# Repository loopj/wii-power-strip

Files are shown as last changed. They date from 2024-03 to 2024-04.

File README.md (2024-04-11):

<p align="center">
  
  
</p>

<h3 align="center">Slimline PCB to supply power to trimmed Wii motherboards</h3>

<p align="center">
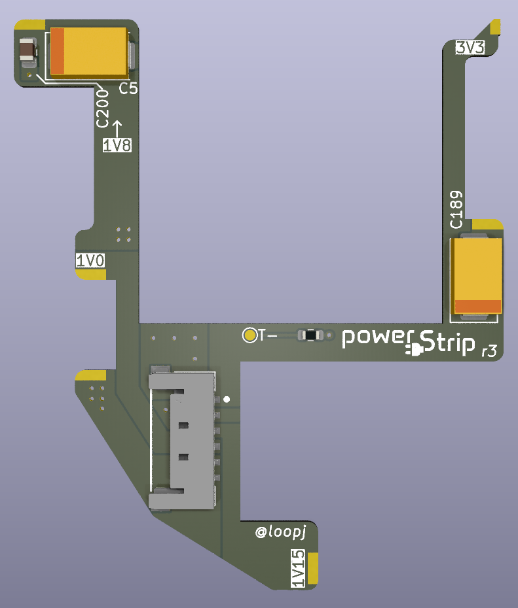
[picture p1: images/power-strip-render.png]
  
</p>

## Features

- Solders directly onto the top of a Wii motherboard
- Supplies power to the 1V, 1.15V, 1.8V, and 3.3V points
- Power connector allows for modular builds without soldering/desoldering wires
- Adds pads for the relocation of capacitors (C5, C189, C200) typically removed on more aggressive trims
- Pad for an optional thermistor, for compatibility with [4Layer Technologies RVL-PMS](https://4layertech.com/products/rvl-pms-2)
- Fits entirely within the outline of an Omega trim
- Fits under heatplates/heatsinks

## Parts / Ordering

- Grab the Gerber files for the [latest release](https://github.com/loopj/wii-power-strip/releases/latest)
- Order a 2-layer, 0.6mm PCB from JLCPCB or similar fab
- Purchase a 6-pin Molex Pico-Lock connector, PN 504050-0691 ([DigiKey](https://www.digikey.com/en/products/detail/molex/5040500691/4357148), [Mouser](https://www.mouser.com/ProductDetail/Molex/504050-0691?qs=bvCPb%252BE7ys2K1LQC9e%2FvRg%3D%3D))
- Purchase either a pre-assembled cable, or parts to crimp your own
  - 50mm pre-assembled cable, PN 15132-0600 ([DigiKey](https://www.digikey.com/en/products/detail/molex/0151320600/7423256), [Mouser](https://www.mouser.com/ProductDetail/Molex/15132-0600?qs=HXFqYaX1Q2wQ%2F2lUgfK5Kw%3D%3D))
  - 100mm pre-assembled cable, PN 15132-0601 ([DigiKey](https://www.digikey.com/en/products/detail/molex/0151320601/7423257), [Mouser](https://www.mouser.com/ProductDetail/Molex/15132-0601?qs=HXFqYaX1Q2xvCBLpk4R9sg%3D%3D))
  - Connector, PN 504051-0601 ([DigiKey](https://www.digikey.com/en/products/detail/molex/5040510601/4357150), [Mouser](https://www.mouser.com/ProductDetail/Molex/504051-0601?qs=bvCPb%252BE7ys2KoBFgs2%2FzNw%3D%3D))
  - Crimp terminals, PN 504052-0098 ([DigiKey](https://www.digikey.com/en/products/detail/molex/5040520098/4357152), [Mouser](https://www.mouser.com/ProductDetail/Molex/504052-0098-Cut-Strip?qs=lzT3SgJKZn3tXLBIQ9V4FQ%3D%3D))
- Optional - 10KΩ thermistor with a 3380K B value, in an 0603 SMD package

## Installation

- If you are doing a motherboard trim that will trim off C5 or C189, desolder these and save them
- If you are doing a NAND relocation which removes C200, desolder this and save it
- Solder the connector and any rescued capacitors to the board by hand or using a hot plate
- Place board on the Wii motherboard, it should self-align
- Solder the pads on the edge of the board to the Wii motherboard
  - 1V0 to the top of C143
  - 1V15 to the left of C17
  - 1V8 to the via array at the top left. You may wish to scratch away some solder mask to have more copper to solder to.
  - 3V3 to the top of C128
  - GND to the bottom of C180 and C143
- Use plenty of solder and flux!

## C189 height

Some motherboard revisions have a very tall (~2.9mm) C189 capacitor, which can interfere with heatplates if you are relocating it. If you have one of these boards, you may wish to consider purchasing a lower profile capacitor. As long as it is a 220uF, 6.3V+, 2917 or 2312 SMD package capacitor it should work fine. The Kyocera AVX NOJY227M006RWJ is a low profile version of the original cap used on the Wii. The TAJX227K006RNJ or TAJY227K006RNJ should also both work.

## RVL-PMS Companion Board

If you want to use Power Strip with the 4Layer Technologies [RVL-PMS-2](https://4layertech.com/products/rvl-pms-2), or [RVL-PMS-Lite](https://4layertech.com/products/pms2-lite) boards, [Y2K](https://github.com/y2k-x) has kindly designed a carrier board called the *Power Strip PMS Companion*, which is included in this repository for convenience.

You can read more about it in the [pms-companion](pms-companion) directory.

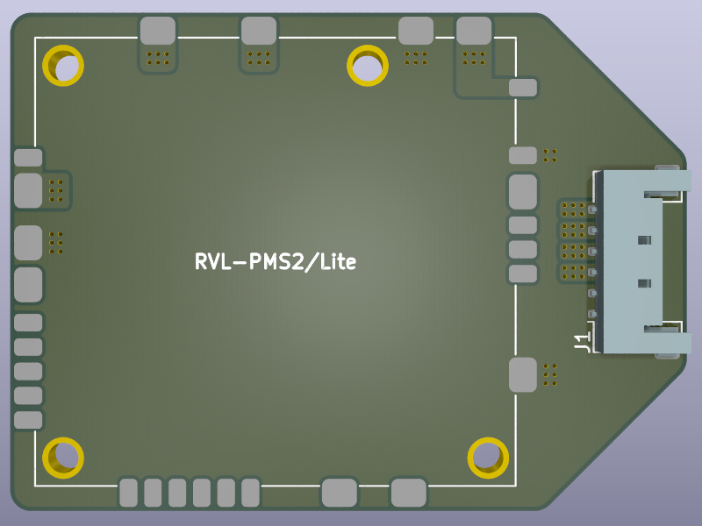
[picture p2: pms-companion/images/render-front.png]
Power Strip PMS Companion


## License

Permissively released under the Solderpad Hardware License v2.1

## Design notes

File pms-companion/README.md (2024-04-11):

# Power Strip PMS Companion

A carrier board for the 4Layer Technologies [RVL-PMS-2](https://4layertech.com/products/rvl-pms-2), or [RVL-PMS-Lite](https://4layertech.com/products/pms2-lite) boards which adds a pico-lock connector for the Wii Power Strip. Designed by [Y2K](https://github.com/y2k-x).

Power Strip PMS Companion front

## Parts / Ordering

- Grab the Gerber files from the [latest release](https://github.com/loopj/wii-power-strip/releases/latest)
- Order a 2-layer PCB from JLCPCB or similar fab, of desired thickness
- Order a [RVL-PMS-2](https://4layertech.com/products/rvl-pms-2) or [RVL-PMS-Lite](https://4layertech.com/products/pms2-lite)
- Purchase a 6-pin Molex Pico-Lock connector, PN 504050-0691 ([DigiKey](https://www.digikey.com/en/products/detail/molex/5040500691/4357148), [Mouser](https://www.mouser.com/ProductDetail/Molex/504050-0691?qs=bvCPb%252BE7ys2K1LQC9e%2FvRg%3D%3D))

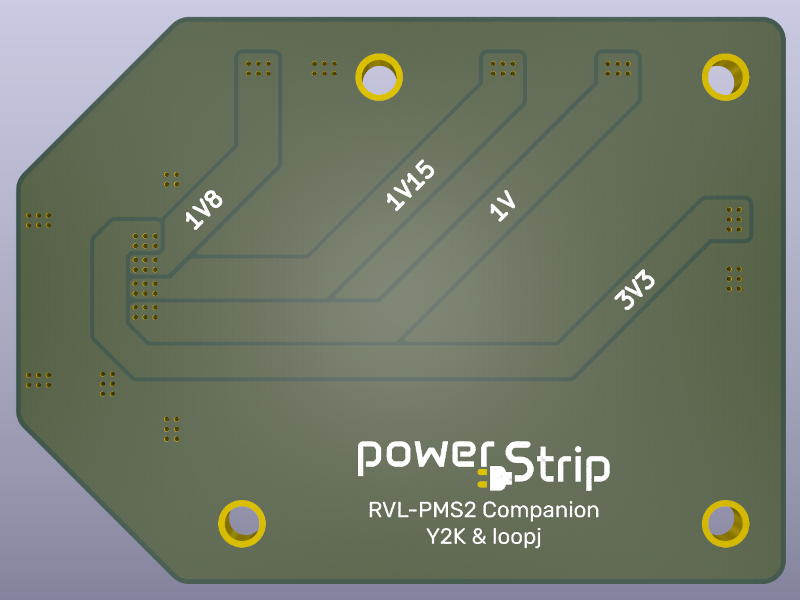
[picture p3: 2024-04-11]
pms-companion/images/render-back.png

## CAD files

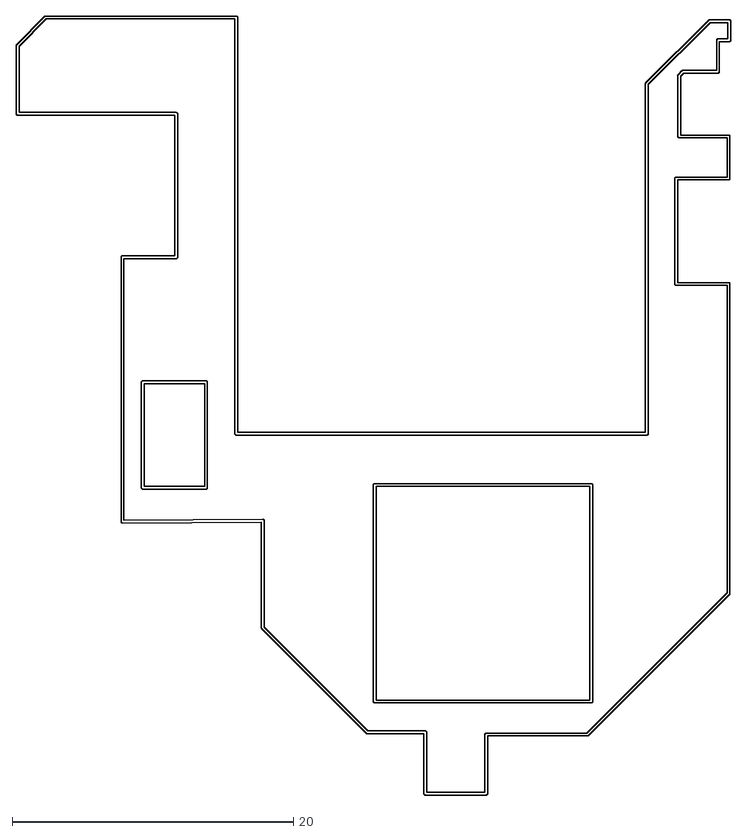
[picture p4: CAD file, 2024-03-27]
images/full-outline.dxf
50.8 x 55.4

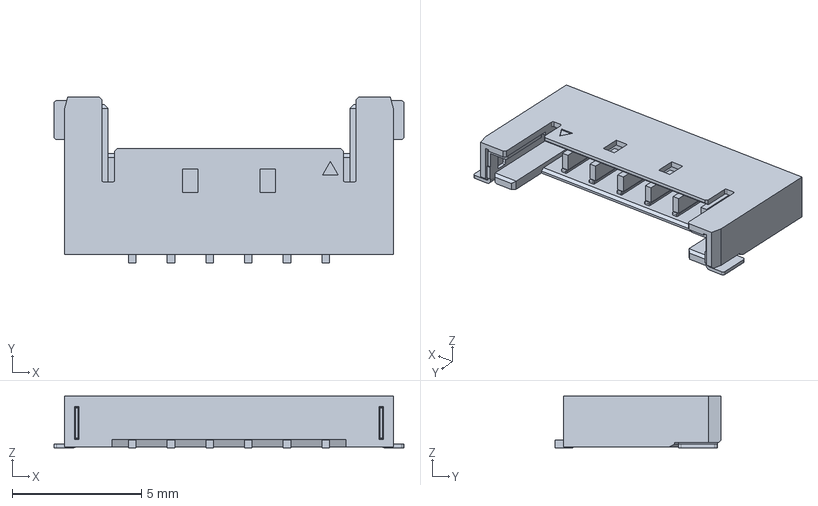
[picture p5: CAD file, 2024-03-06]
pms-companion/KiCad/project-footprints/504050-0691.stp
13.6 x 6.44 x 2.00 mm

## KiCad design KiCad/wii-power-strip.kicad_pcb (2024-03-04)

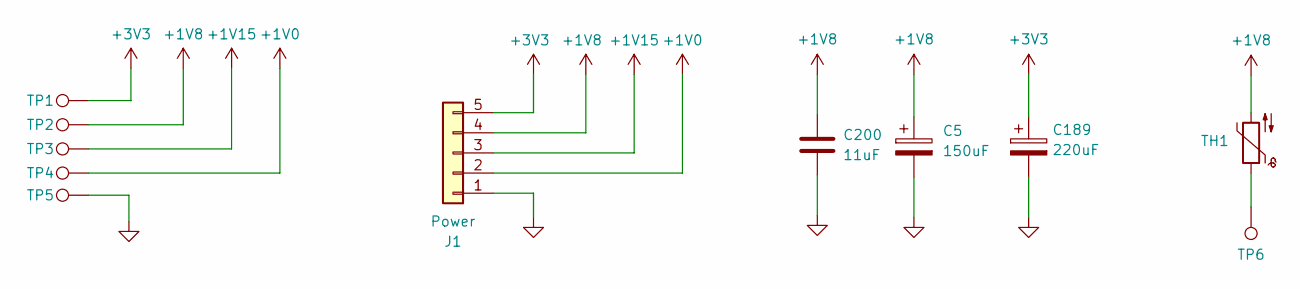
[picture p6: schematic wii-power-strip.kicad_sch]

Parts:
C5: 150uF; CP_EIA-7343-20_Kemet-V
C189: 220uF; CP_EIA-7343-20_Kemet-V
C200: 11uF
J1: Power; 5040500591
TH1: Thermistor_NTC; R_0603_1608Metric
TP1: 3V3; TestPoint_Pad_1.5x1.0mm
TP2: 1V8; TestPoint_Pad_3x1.0mm
TP3: 1V15; TestPoint_Pad_3x1.0mm
TP4: 1V0; TestPoint_Pad_3x1.0mm
TP5: GND; TestPoint_Pad_3x1.0mm
TP6: T-; TestPoint_Pad_D1.0mm

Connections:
+1V0: J1.2, TP4.1
+1V8: C5.1, C200.1, J1.4, TH1.2, TP2.1
+1V15: J1.3, TP3.1
+3V3: C189.1, J1.5, TP1.1
GND: C5.2, C189.2, C200.2, J1.1, TP5.1
unnamed: TH1.1, TP6.1

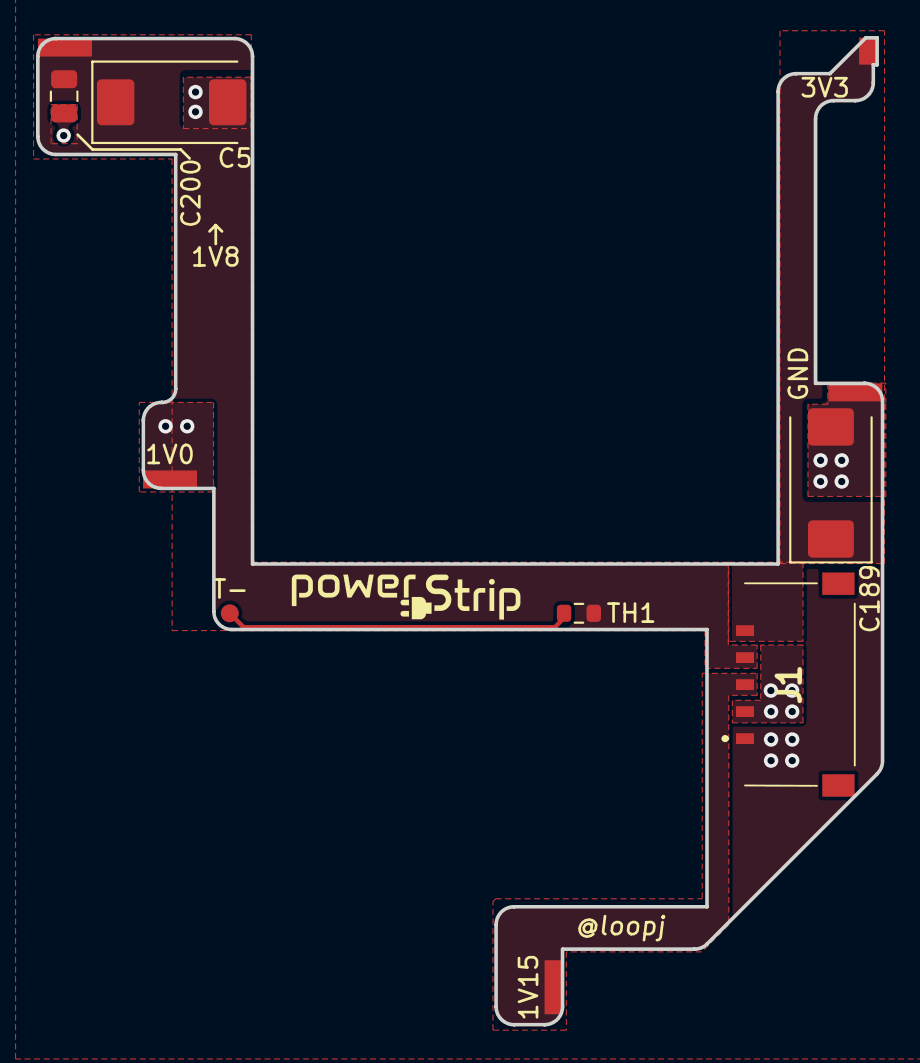
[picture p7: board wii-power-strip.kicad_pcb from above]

Board: 2 copper layers, 46.9 x 54.8 mm, 11 parts (0 on the bottom side), 6 nets.

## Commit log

2024-03-04 Add power strip render with logo
2024-03-04 Link to gerber zip from README
2024-03-05 Left facing, 6-pin power connector
    [504050-0591.stp, 504050-0691.stp, wii-power-strip.kicad_sch]
2024-03-27 Fix clearance issue with connector and cap
2024-03-27 Add dxf of full outline in case people want to make custom outlines
    [full-outline.dxf]
2024-04-11 Add pms companion to repo
    [504050-0691.stp, pms-companion.kicad_pcb, pms-companion.kicad_sch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]
2024-04-11 Add README, restructure
    [504050-0691.stp, pms-companion.kicad_pcb, pms-companion.kicad_sch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]
2024-04-11 Fix 3d model references
    [504050-0691.stp, pms-companion.kicad_pcb]
